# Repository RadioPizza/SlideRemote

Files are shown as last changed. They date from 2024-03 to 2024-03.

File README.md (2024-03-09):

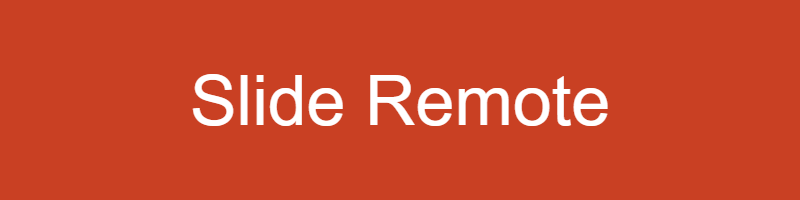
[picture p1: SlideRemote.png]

# Пульт для презентаций на ESP8266
## Содержание
* [Описание проекта](#chapter-0)
* [Папки проекта](#chapter-1)
* [Схемы подключения](#chapter-2)
* [Материалы и компоненты](#chapter-3)
* [Как скачать и прошить](#chapter-4)
* [Обратная связь](#chapter-5)

## Описание проекта
Представляем вашему вниманию пульт для выступлений с презентациями на основе ESP8266! Основные преимущества проекта перед импортными аналогами из масс-маркета - низкая цена и безграничные возможности для кастомизации. Вы можете создать для него индвидуальный корпус любой формы из любых материалов и добавить аппаратные и/или программные функции, которые нужны именно вам.

### Схема электрическая структурная
StructuralCircuit

### Железо
- Проект собран на базе пары микроконтроллеров ESP8266. Для передачи данных между ними используется ESP-NOW (упрощенный протокол связи WiFi с передачей коротких пакетов между парами сопряженных устройств).
- Для реализации USB HID используется микроконтроллер Attiny85 за неимением у ESP8266 аппаратного USB (можно попробовать отказаться от AVR костыля, используя V-USB, проект открыт для ваших PR). Attiny85 подключается к принимающей ESP четырьмя проводами: пара для питания и пара для передачи данных. Передача данных реалзована весьма примитивно, так как требуется лишь отслеживание логических состояний (нажата/не нажата) для двух кнопок.

### Фишки
- Пара кнопок для навигации по слайдам: "впёрёд" и "назад"
- Интегрированная лазерная указка
- Автономное питание от литиевого аккумулятора и встроенная зарядка для него - батарейки не понадобятся!
- Быстрое соединение благодаря ESP-NOW - ничего устанавливать на компьютер и настраивать перед выступлением не нужно!

## Папки
- **circuits** - электрические схемы
- **datasheets** - техническая документация на используемые компоненты
- **firmware** - прошивки для микроконтроллеров
- **libraries** - все необходимые библиотеки, испрользуемые в коде

## Схемы
### Схема электрическая функциональная
FunctionalCircuit

### Схема макета
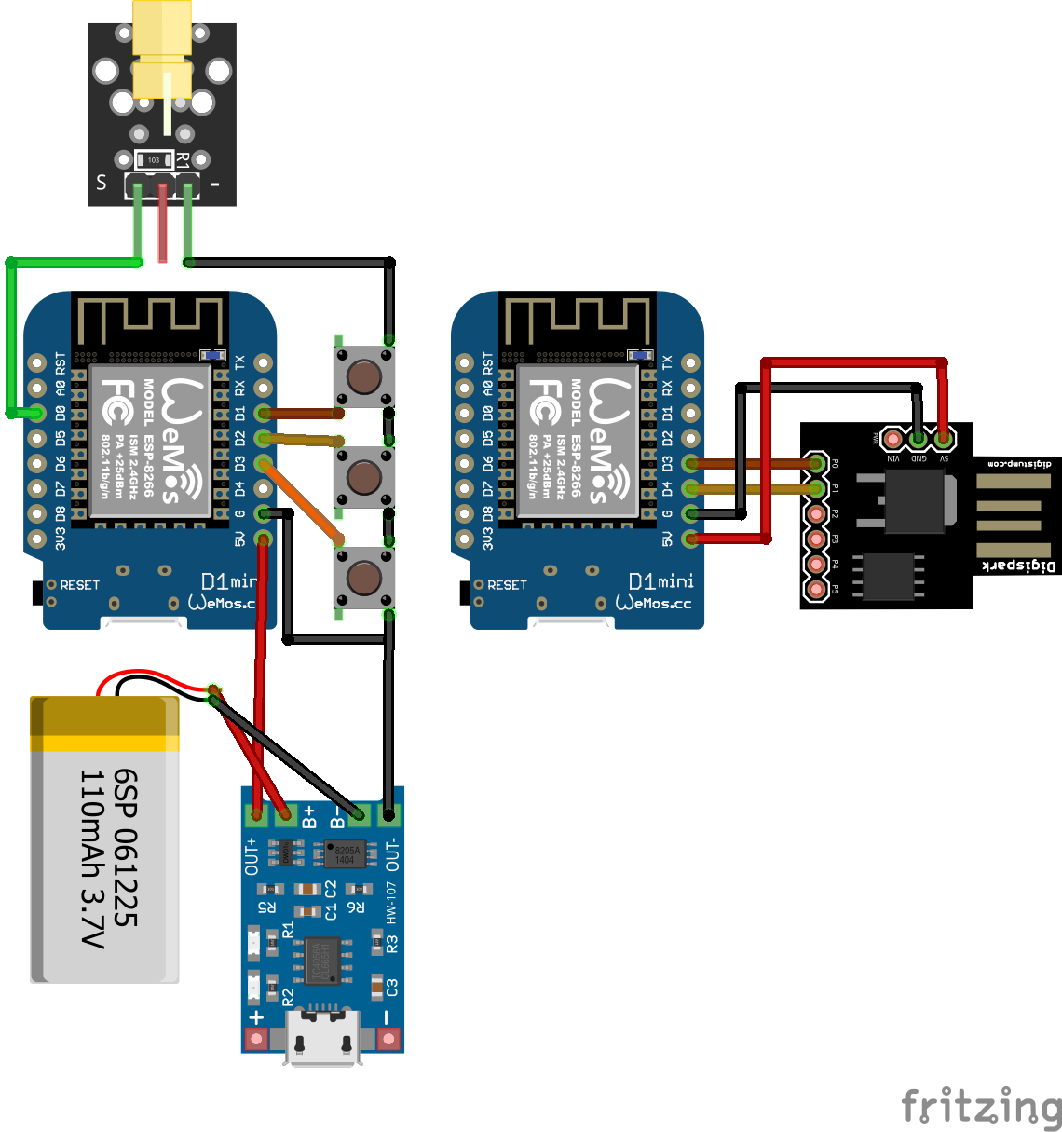
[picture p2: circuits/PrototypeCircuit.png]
PrototypeCircuit


## Материалы и компоненты
| Наименование | Цена  | Кол-во | Стоимость | Ссылка | Комментарий |
|---|---|---|---|---|---|
| Wemos D1 Mini | 150 ₽ | 2 шт.  | 300 ₽ | https://aliexpress.ru/item/1005004691735010.html?sku_id=12000030118892637&spm=.search_results.2.b5fe6debne6nar https://aliexpress.ru/item/1005001621784437.html?sku_id=12000030876907542&spm=.search_results.0.b5fe6debne6nar | Можно использовать любые другие отладочные платы на базе ESP8266 |
| Кнопки | 5 ₽ | 3 шт.  | 15 ₽ | https://aliexpress.ru/item/1005002483504604.html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 https://aliexpress.ru/item/32815841388.html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 | Подойдут абсолютно любые |
| Лазерный диод | 30 ₽  | 1 шт.  | 30 ₽ | https://aliexpress.ru/item/32436757591.html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 https://aliexpress.ru/item/590519565.html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 | 5 В, 5 мВт, 650 нм |
| Модуль зарядки TP4056 | 30 ₽  | 1 шт.  | 30 ₽ | https://aliexpress.ru/item/32467578996.html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 https://aliexpress.ru/item/1005005741783050.html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 | Необходимо выбирать со встроенной схемой защиты |
| Аккумулятор | 250 ₽ | 1 шт.  | 250 ₽ | https://aliexpress.ru/item/1005005684424738.html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 https://aliexpress.ru/item/4000939330410.html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 | Можно использовать аккумуляторы из одноразок |
| Digispark | 250 ₽ | 1 шт.  | 250 ₽ | https://aliexpress.ru/item/32807895683.html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 https://aliexpress.ru/item/1005004203065658.html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 | |
| Переключатель | 20 ₽  | 1 шт.  | 20 ₽ | https://aliexpress.ru/item/4001202080623.html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 https://aliexpress.ru/item/1005001513148147.html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 | Нужен для отключения питания |

Можно вместо одной из плат Wemos D1 Mini и платы TP4056 использовать очень интересную плату [ESP-Wroom-02 D1 Mini + 18650](https://aliexpress.ru/item/33060514583.html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), представляющую собой ESP8266 со встроенной зарядкой для литиевых аккумуляторов и холдером для аккумуляторов 18650.

Итоговая стоимость варьируется от **450 рублей** (при покупке мелким оптом и повторном использовании кнопок и аккумулятора) до **2000 рублей** (при покупке в розницу в местных магазинах и использовании нового большого аккумулятора)

## Как скачать и прошить
1. Установить и запустить Arduino IDE - [официальный сайт](https://www.arduino.cc/en/software')
2. Установить драйвера для контроллеров:
  * CH340/CH341 - [официальный сайт](https://wch-ic.com/downloads/CH341SER_EXE.html)
  * CP2102 - [официальный сайт](https://www.silabs.com/developers/usb-to-uart-bridge-vcp-drivers)
3. Добавить допополнительные ссылки для менеджера плат:
  * `Arduino IDE/Файл/Настройки/Дополнительные ссылки …` добавить через `,`
    - `http://arduino.esp8266.com/stable/package_esp8266com_index.json`
    - `https://raw.githubusercontent.com/digistump/arduino-boards-index/master/package_digistump_index.json`
4. Установить в менеджере плат:
  * `ESP8266 boards` рекомендуется версия 2.7.4
  * `Digistump AVR Boards` рекомендуется версия 1.6.7
5. Скачать архив с проектом (зелёная кнопка Code/Download ZIP)
6. Установить библиотеки (заменить имеющиеся версии) в 
  * `C:\Program Files (x86)\Arduino\libraries\` (Windows x64)  
  * `C:\Program Files\Arduino\libraries\` (Windows x86)
7. По очереди открыть файлы прошивки для каждого из микроконтроллеров, выбирая использумые платы и порт, прошить их
  * `LOLIN Wemos D1 R2 & mini` изменяйте в зависимости от используемой платы
  * `Digispark (Default – 16.5mhz)` ДО ПОДКЛЮЧЕНИЯ платы нажимаем загрузка, ждём компиляции. Появится надпись “подключите плату”. Втыкаем плату в USB и прошивка загружается.

### Настройки в коде
#### SlideRemoteTX.ino
```cpp
// Настройка пинов подключения
#define BTN_PREV_PIN 5   // это D1 на Wemos
#define BTN_NEXT_PIN 4   // это D2 на Wemos
#define BTN_LASER_PIN 0  // это D3 на Wemos
#define LED_LASER_PIN 16 // это D0 на Wemos

// MAC адрес приёмника
uint8_t broadcastAddress[] = {0x48, 0x55, 0x19, 0xDE, 0xB3, 0x6B};
```
#### SlideRemoteRX.ino
```cpp
// Настройка пинов подключения
#define PREV_PIN 2 // это D4 на Wemos
#define NEXT_PIN 0 // это D3 на Wemos
```
#### SlideRemoteHID.ino
```cpp
// Настройка пинов подключения
#define PREV_PIN 0
#define NEXT_PIN 1
```

## Обратная связь
Ваши предложения и дополнения к проекту приветствуются! При нахождении багов создавайте **Issue** (описание проблемы, используемое железо, используемое ПО).

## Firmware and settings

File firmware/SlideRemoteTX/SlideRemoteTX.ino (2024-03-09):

// SlideRemote v1.0.1
// TX - Передатчик

// Подключение библиотек
#include <EncButton.h>
#include <ESP8266WiFi.h>
#include <espnow.h>

// Настройка пинов подключения
#define BTN_PREV_PIN 5   // это D1 на Wemos
#define BTN_NEXT_PIN 4   // это D2 на Wemos
#define BTN_LASER_PIN 0  // это D3 на Wemos
#define LED_LASER_PIN 16 // это D0 на Wemos

Button buttonPrev(BTN_PREV_PIN);
Button buttonNext(BTN_NEXT_PIN);
Button buttonLaser(BTN_LASER_PIN);

// MAC адрес приёмника
uint8_t broadcastAddress[] = {0x48, 0x55, 0x19, 0xDE, 0xB3, 0x6B};

// Структура для отправки данных
struct StructMessage {
  bool buttonNext;
  bool buttonPrev;
};

StructMessage myData;

void setupWiFi() {
  WiFi.mode(WIFI_STA); 
  if (esp_now_init() != 0) {
    Serial.println("Error initializing ESP-NOW");
    return;
  }
  esp_now_set_self_role(ESP_NOW_ROLE_CONTROLLER);
  esp_now_add_peer(broadcastAddress, ESP_NOW_ROLE_SLAVE, 1, NULL, 0);
  Serial.println("WiFi Setup completed successfully");
}

void setup() {
  Serial.begin(9600);
  pinMode(LED_LASER_PIN, OUTPUT);
  setupWiFi();
  Serial.println("Initialization completed successfully");
}

void updateButtonsState(bool next, bool prev) {
  myData.buttonNext = next;
  myData.buttonPrev = prev;
  
  if (esp_now_send(broadcastAddress, (uint8_t *)&myData, sizeof(myData)) != 0) {
    Serial.println("Error sending the data");
  }
}

void handleLaserButton() {
  if (buttonLaser.press()) {
    digitalWrite(LED_LASER_PIN, HIGH);
    Serial.println("Laser ON");
  } else if (buttonLaser.release()) {
    digitalWrite(LED_LASER_PIN, LOW);
    Serial.println("Laser OFF");
  }
}

void handleSlideButtons() {
  const bool nextClicked = buttonNext.click();
  const bool prevClicked = buttonPrev.click();
  
  if (nextClicked || prevClicked) {
    updateButtonsState(nextClicked, prevClicked);
    Serial.println(nextClicked ? "Button Next was clicked" : "Button Prev was clicked");
  }
}

void loop() {
  buttonPrev.tick();
  buttonNext.tick();
  buttonLaser.tick();
  handleSlideButtons();
  handleLaserButton();
}

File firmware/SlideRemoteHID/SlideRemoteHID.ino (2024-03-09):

// SlideRemote v1.0.1
// USB HID

// Подключение библиотеки
#include <DigiKeyboard.h>

// Настройка пинов подключения
#define PREV_PIN 1
#define NEXT_PIN 0

void setup() {
  pinMode(PREV_PIN, INPUT);
  pinMode(NEXT_PIN, INPUT);
}

void loop() {
  if (digitalRead(PREV_PIN)){
    DigiKeyboard.sendKeyStroke(KEY_ARROW_LEFT);
    DigiKeyboard.delay(10);
  }
  
  if (digitalRead(NEXT_PIN)){
    DigiKeyboard.sendKeyStroke(KEY_SPACE);
    DigiKeyboard.delay(10);
  }
}                                                                                                                                                                                                                                                                                                                                         

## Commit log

2024-03-05 Change lib for HID, fix bugs
    [SlideRemoteHID.ino, SlideRemoteRX.ino]
2024-03-09 Add structural circuit
2024-03-09 Add functional circuit
2024-03-09 Update functional circuit
2024-03-10 Update prototype circuit
    [PrototypeCircuit.fzz]
